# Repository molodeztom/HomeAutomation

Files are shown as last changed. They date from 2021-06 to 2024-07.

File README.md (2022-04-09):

# HomeAutomation
Specifications:
several remote sensors with ESP8266 type a with temperature type b with humidity and temperature
remote sensors shall save energy thus using sleep mode and esp-now protocol
remote sensors report battery voltage
home server as receiver for esp-now and in combination with serial connection to weather station acts as bridge between esp-now and wifi
weather station as receiver, displays values on OLED and provides MQTT messages with measurement values
MQTT is received on a raspberry
raspberry with docker images uses node-red to write mqtt measurements to influx db. Displays values from influx db in grafana.
valve control is esp8266 hardware controlling a valve for central heating goal is to reduce warm water input depending on room temperatures and each radiator valve
remote display is a simple mqtt receiver with OLED to display outdoor temp and humidity

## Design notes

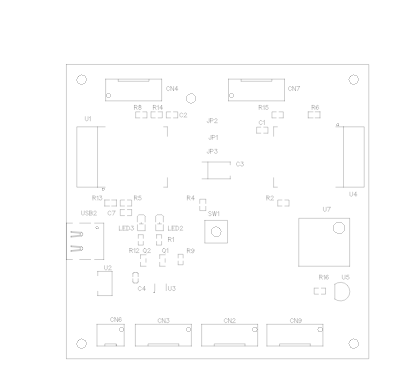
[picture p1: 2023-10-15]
HubESPNow/EasyEDA/PCB_PCB_EspNowHub_2023-02-25.png

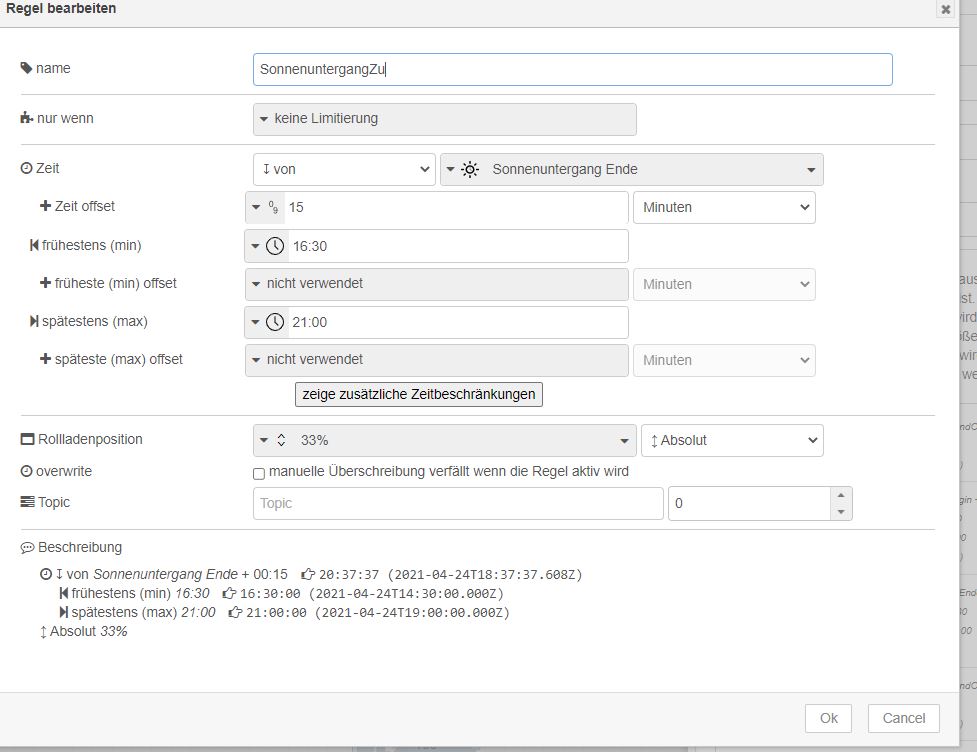
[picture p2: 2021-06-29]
ShutterControl/SonnenUntergangZuTüre.JPG

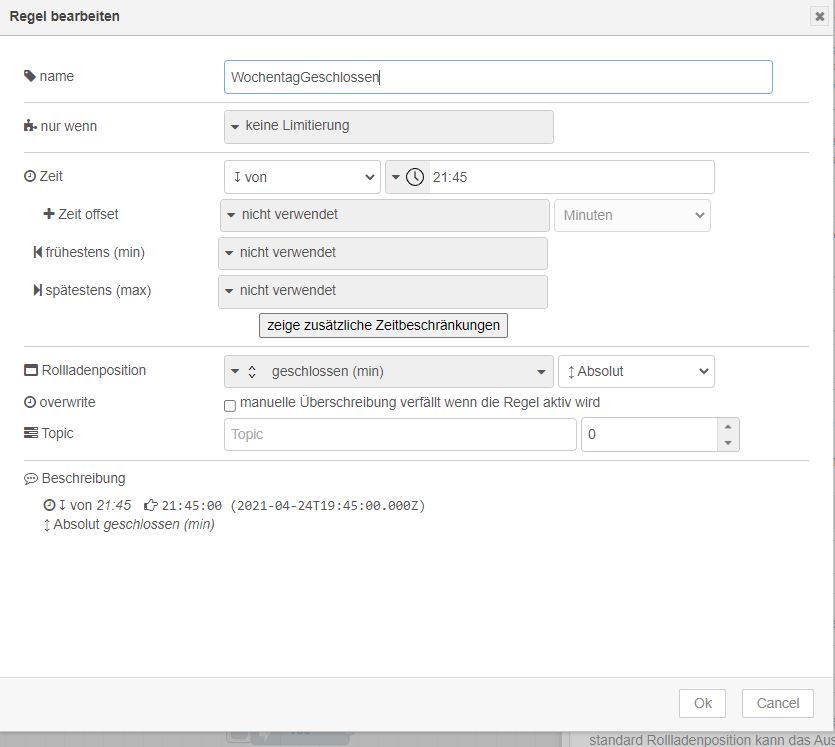
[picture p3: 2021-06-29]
ShutterControl/WochentagGeschlossenTür.JPG

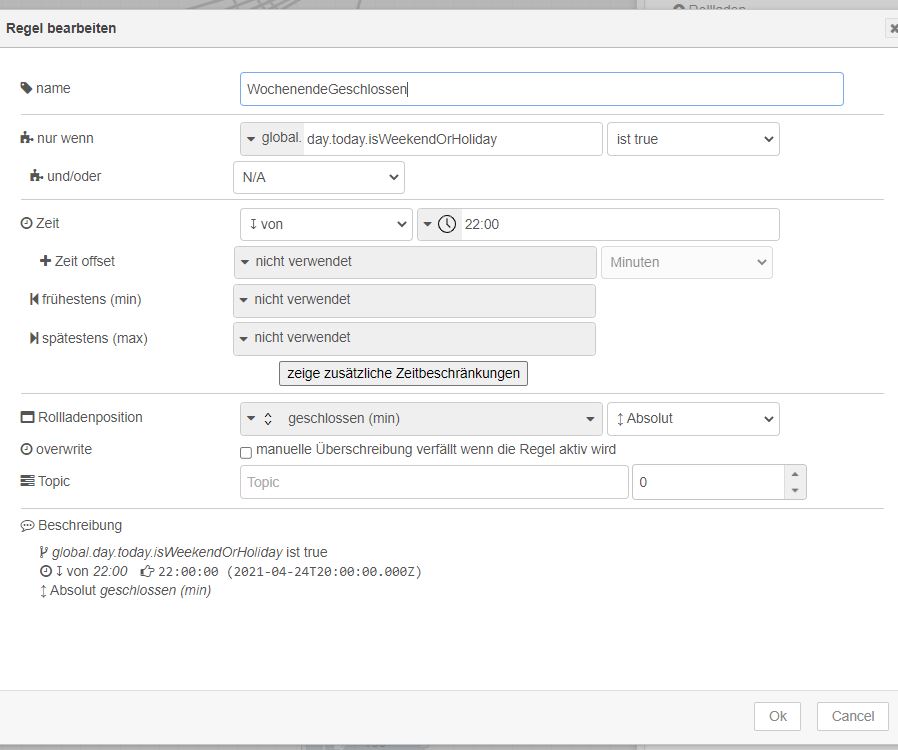
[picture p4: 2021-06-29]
ShutterControl/WochenendeGeschlossenTür.JPG

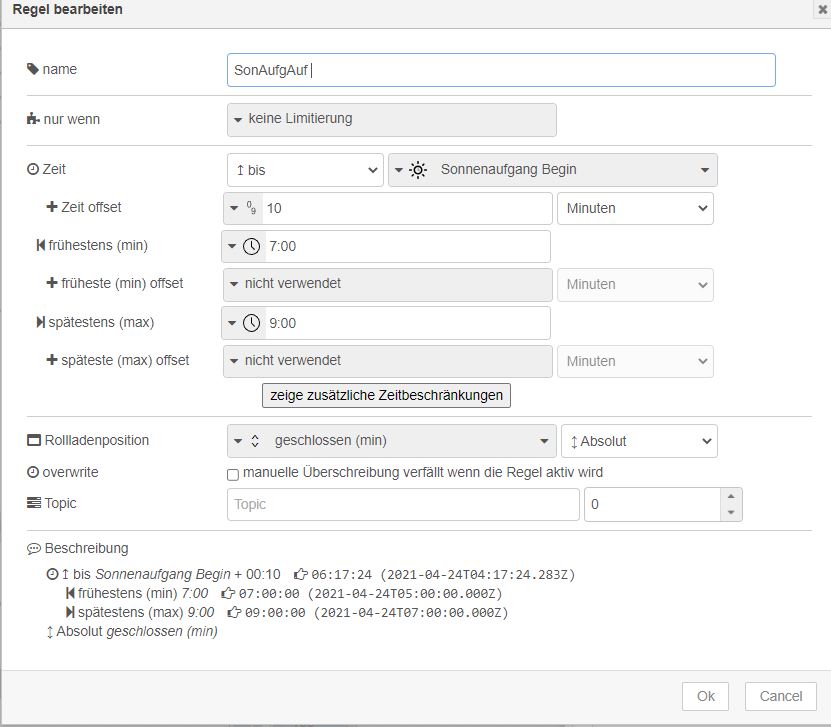
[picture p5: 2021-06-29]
ShutterControl/SonAufgAufTüre.JPG

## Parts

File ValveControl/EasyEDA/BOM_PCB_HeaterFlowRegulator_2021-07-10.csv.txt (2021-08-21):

ID	Name	Designator	Footprint	Quantity	Pins
1	12V ok	12V	LED-SMD_L3.2-W2.8-R-RD	1	2
2	5V ok	5V	LED-SMD_L3.2-W2.8-R-RD	1	2
3	3V ok	3V	LED-SMD_L3.2-W2.8-R-RD	1	2
4	442	R10	R0603	1	2
5	91	R11	R0603	1	2
6	LM358PSR	U5	SOIC-8_L6.2-W5.3-P1.27-LS8.0-BL	1	8
7	Program	CN6	CONN-TH_B5B-XH-AM (LF)(SN)	1	5
8	Reset	SW1	KEY-SMD_4P-L6.0-W6.0-P4.50-LS10.0	1	4
9	ESP8266-12E	U1	LGA22-2.0-24X16MM	1	22
10	Fuse 1A	F1	FUSE-TH_L22.6-W9.0	1	2
11	ext Sensor	TEMP1,TEMP2	CONN-TH_3P-P2.50_B3B-XH-AM(LF)(SN)	2	3
12	MCP4725A0T-E/CH	U4	SOT-23-6_L2.9-W1.6-P0.95-LS2.8-BR	1	6
13	10K	R3,R2	603	2	2
14	10K	R6,R5,R4	603	3	2
15	100nF	C2,C4	C0603	2	2
16	LF33CDT-TR	U2	TO-252-2_L6.6-W6.1-P4.57-LS9.9-BR-CW	1	3
17	0	R7,R8	R0603	2	2
18	PA001-2P	CN4,CN3	CONN-TH_2P-P5.08_PA001-2P	2	2
19	100nF	C6	603	1	2
20	100nF	C7	603	1	2
21	0	R12,R9	R0603	2	2
22	10k	RP1	RES-ADJ-TH_3386P	1	3
23	Tenstar_PSU	PSU1,PSU2	AC-DC PSU 5V/3W	2	4
24	Display	CN7	CONN-TH_B5B-XH-AM (LF)(SN)	1	5
25	Valve Ctrl	CN2	CONN-TH_2P-P5.08_PA001-2P	1	2
26	AC 220V	CN1	CONN-TH_2P-P5.08_PA001-2P	1	2
27	LightSensor	CN8	CONN-TH_B5B-XH-AM (LF)(SN)	1	5
28	220uF	C1,C3	CAP-TH_BD8.0-P3.50-D0.6-FD	2	2
29	100uF	C5	CAP-SMD_L3.5-W2.8	1	2

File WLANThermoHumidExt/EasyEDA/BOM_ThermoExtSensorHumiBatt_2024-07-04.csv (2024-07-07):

ID | Name | Designator | Footprint | Quantity | Manufacturer Part | Manufacturer | Supplier | Supplier Part | Price
1 | 100nF | C1,C3,C4,C5,C11 | 0603 | 5 | CL10B104KC8NNNC | SAMSUNG | LCSC | C15725 | 0.007
2 | 100uF | C2 | CAP-SMD_L7.3-W4.3 | 1 | TAJB107K006RNJ | AVX | LCSC | C16133 | 0.142
3 | 1uF | C6,C7 | C0603 | 2 | CL10A105KA8NNNC | SAMSUNG | LCSC | C5673 | 0.004
4 | 100nF | C8 | C0603 | 1 | CL10F104ZB8NNNC | SAMSUNG | LCSC | C1688 | 0.005
5 | 10uF | C9,C10 | C1206 | 2 | CL31A106KAHNNNE | SAMSUNG | LCSC | C9807 | 0.019
6 | Program | CN1 | CONN-TH_B5B-XH-AM (LF)(SN) | 1 | - | JST Sales America | LCSC | C161872 | 0.088
7 | B2B-XH-AM (LF)(SN) | CN3 | CONN-TH_B2B-XH-AM (LF)(SN) | 1 | - | JST Sales America | LCSC | C161869 | 0.052
8 | SS14_C84343 | D2 | SMA_L4.3-W2.6-LS5.2-RD | 1 | SS14 | STARSEA | LCSC | C84343 | 0.023
9 | green | LED3 | LED0805-FD | 1 | FC-2012UGK-520D5 | NATIONSTAR | LCSC | C84260 | 0.019
10 | red | LED4 | LED0805-FD | 1 | FC-2012UGK-520D5 | NATIONSTAR | LCSC | C84260 | 0.019
11 | 8205A | Q2 | TSSOP-8_L4.4-W3.0-P0.65-LS6.4-BL | 1 | 8205A | Hottech | LCSC | C181100 | 0.059
12 | 10K | R1,R2,R3,R4,R5,R6 | 0603 | 6 | TC0325B1002T5E | UniOhm | LCSC | C39050 | 0.041
13 | 100K | R7 | R0603 | 1 | TC0350B1003T5E | UNI-ROYAL(Uniroyal Elec) | LCSC | C415126
14 | 1K | R8,R14,R15 | R0603 | 3 | TC0350D1001T5E | Uniroyal Elec | LCSC | C165976 | 0.008
15 | 100 | R9 | R0603 | 1 | TC0325B1000T5E | UniOhm | LCSC | C54021 | 0.036
16 | 4.7K | R10 | R0603 | 1 | TC0325B4701T5E | UniOhm | LCSC | C148464 | 0.056
17 | 0 | R11,R12 | R0603 | 2 | 0603WAJ0000T5E | UniOhm | LCSC | C15402 | 0.001
18 | 1.2K | R17 | R0603 | 1 | AR03DTCX1201 | Viking Tech | LCSC | C319998 | 0.013
19 | Reset | SW1 | KEY-SMD_4P-L6.0-W6.0-P4.50-LS10.0 | 1 | TL3301TF160QG/D310794 | E-Switch | LCSC | C273532 | 0.465
20 | ext Sensor | TEMP | CONN-TH_3P-P2.50_B3B-XH-AM(LF)(SN) | 1 | B3B-XH-AM-(LF)(SN) | JST Sales America | LCSC | C161870 | 0.063
21 | ESP8266-12E | U1 | LGA22-2.0-24X16MM | 1 | ESP8266-12E/ESP-12E |  | SeeedStudio | 317060015
22 | DS18B20 | U2 | TO-92(TO-92-3) | 1 | DS18B20+ | MAXIM | LCSC | C9753 | 1.107
23 | XC6206P332MR | U3 | SOT-23-3_L2.9-W1.6-P1.90-LS2.8-BR | 1 | XC6206P332MR | TOREX | LCSC | C5446 | 0.097
24 | DW01A-G | U4 | SOT-23-6_L2.9-W1.6-P0.95-LS2.8-BR | 1 | DW01A-G | FORTUNE | LCSC | C61503 | 0.125
25 | DHT22 | U6 | DHT22_AM2303_VERT | 1 |  | Aosong (Guangzhou) Electronics Co., Ltd. | AdaFruit | PRODUCT ID: 385
26 | MAX708SESA-TG | U7 | SOIC-8_L4.9-W3.9-P1.27-LS6.0-BL | 1 | MAX708SESA-TG | ON Semicon | LCSC | C233649
27 | TP4056_C382139 | U8 | ESOP-8_L4.9-W3.9-P1.27-LS6.0-BL-EP | 1 | TP4056 | TPOWER | LCSC | C382139 | 0.094
28 | USB-306 | USB1 | USB-TYPE-C-TH_USB-306 | 1 | USB-306 | HOOYA | LCSC | C309338 | 0.607

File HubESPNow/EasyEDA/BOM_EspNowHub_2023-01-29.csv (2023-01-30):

ID | Name | Designator | Footprint | Quantity | Manufacturer Part | Manufacturer | Supplier | Supplier Part | Price
1 | 100nF | C1,C2 | 0603 | 2 | CL10B104KC8NNNC | SAMSUNG | LCSC | C1688 | 0.001
2 | 100uF | C3 | CAP-SMD_L7.3-W4.3-R-RD | 1 | CA45-D-16V-100UF-K | CEC | LCSC | C129274 | 0.068
3 | 100nF | C4 | C0603 | 1 | CL10B104KC8NNNC | SAMSUNG | LCSC | C1688 | 0.001
4 | 100nF | C7 | 0603 | 1 | CL10B104JB8NNNC | SAMSUNG | LCSC | C1688 | 0.001
5 | LightSensor | CN2 | CONN-TH_B5B-XH-AM (LF)(SN) | 1 | - | JST Sales America | LCSC | C161872 | 0.015
6 | Display | CN3,CN9 | CONN-TH_B5B-XH-AM (LF)(SN) | 2 | - | JST Sales America | LCSC | C161872 | 0.015
7 | Program 2 | CN4 | CONN-TH_B5B-XH-AM (LF)(SN) | 1 | - | JST Sales America | LCSC | C161872 | 0.015
8 | +5V Batt | CN6 | CONN-TH_B2B-XH-AM-LF-SN | 1 | - | JST Sales America | LCSC | C161869 | 0.009
9 | Program 1 | CN7 | CONN-TH_B5B-XH-AM (LF)(SN) | 1 | - | JST Sales America | LCSC | C161872 | 0.015
10 | RX | JP1 | SPARKFUN-JUMPERS_SMT-JUMPER_2_NC_PASTE_NO-SILK | 1
11 | TX | JP2 | SPARKFUN-JUMPERS_SMT-JUMPER_2_NC_PASTE_NO-SILK | 1
12 | RX Ext | JP3 | SPARKFUN-JUMPERS_SMT-JUMPER_2_NC_PASTE_NO-SILK | 1
13 | 3V OK red | LED2 | LED0805-R-RD | 1 | 17-21SURC/S530-A3/TR8 | EVERLIGHT | LCSC | C72037 | 0.003
14 | 5V USB blue | LED3 | LED0805-R-RD | 1 | FC-2012UGK-520D5 | NATIONSTAR | LCSC | C84260 | 0.003
15 | DMP1045U-7 | Q1,Q2 | SOT-23-3_L2.9-W1.3-P1.90-LS2.4-BR | 2 | DMP1045U-7 | Diodes Incorporated | LCSC | C177033 | 0.061
16 | 210Ω | R1 | R0603 | 1 | 0603WAF2100T5E | UniOhm | LCSC | C22953
17 | 10K | R2,R14,R16 | 0603 | 3 | TC0325B1002T5E | UniOhm | LCSC | C39050 | 0.006
18 | 10K | R4,R5,R8,R15 | 0603 | 4 | TC0310B1002T5E | Uniroyal Elec | LCSC | C190321 | 0.024
19 | 1MΩ | R9 | R0603 | 1 | 0603WAF1004T5E | UniOhm | LCSC | C22935
20 | 130Ω | R12 | R0603 | 1 | 0603WAF1300T5E | UniOhm | LCSC | C22796
21 | Reset | SW1 | KEY-SMD_4P-L6.0-W6.0-P4.50-LS10.0 | 1 | TL3301TF160QG/D310794 | E-Switch | LCSC | C273532 | 0.083
22 | ESP8266-12E WLAN | U1 | LGA22-2.0-24X16MM | 1 | ESP8266-12E/ESP-12E |  | SeeedStudio | 317060015
23 | AMS1117-3.3 | U2 | PG-SOT223-4_L6.5-W3.5-P2.30-LS7.0-BR | 1 | AMS1117-3.3 | HGC(Huaguan Semicon) | LCSC | C498117
24 | LTC4412ES6 | U3 | TSOT-23-6_L2.9-W1.6-P0.95-LS2.8-BR | 1 | LTC4412ES6#TRPBF | Analog Devices | LCSC | C514442 | 0.467
25 | ESP8266-12E ESP NOW | U4 | LGA22-2.0-24X16MM | 1 | ESP8266-12E/ESP-12E |  | SeeedStudio | 317060015
26 | DS18B20 | U5 | TO-92(TO-92-3) | 1 | DS18B20+ | MAXIM | LCSC | C9753 | 0.195
27 | BMP180 | U7 | BMP180 | 1 | PROJ_LIC Lib
28 | USB-306 | USB2 | USB-TYPE-C-TH_USB-306. | 1 | USB-306 | HOOYA | LCSC | C309338 | 0.099

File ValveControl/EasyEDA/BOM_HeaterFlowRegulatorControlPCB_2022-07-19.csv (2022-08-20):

Designator | Quantity | Name | ID
C1,C2 | 2 | 100nF | 1
CN1 | 1 | In | 2
CN2 | 1 | Out | 3
LED1 | 1 | LED1 rd | 4
LED2 | 1 | LED2 gn | 5
LED3 | 1 | LED3 ye | 6
LED4 | 1 | LED4 bl | 7
Q1,Q2 | 2 | BSS138 | 8
R1,R3 | 2 | 91 | 9
R2,R4 | 2 | 150 | 10
R8,R9,R10 | 3 | 0 | 11
R11,R12,R13,R14 | 4 | 10K | 12
SW1 | 1 | SW1 | 13
SW2 | 1 | SW2 | 14
SW3 | 1 | SW3 | 15
SW4 | 1 | SW4 | 16
U10 | 1 | PCF8574T | 17

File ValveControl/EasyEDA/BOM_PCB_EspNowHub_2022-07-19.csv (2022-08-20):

Designator | Quantity | Name | ID
C1,C2,C7 | 3 | 100nF | 3
C3 | 1 | 100uF | 25
C4 | 1 | 100nF | 5
CN2 | 1 | LightSensor | 6
CN3,CN9 | 2 | Display | 7
CN4 | 1 | Program 2 | 8
CN6 | 1 | +5V Batt | 10
CN7 | 1 | Program 1 | 9
JP1 | 1 | RX | 11
JP2 | 1 | TX | 12
JP3 | 1 | RX Ext | 13
LED2 | 1 | 3V OK red | 14
LED3 | 1 | 5V USB blue | 15
Q1,Q2 | 2 | DMP1045U-7 | 16
R1 | 1 | 210Ω | 17
R12 | 1 | 130Ω | 18
R2,R4,R5,R8,R14,R15,R16 | 7 | 10K | 4
R9 | 1 | 1MΩ | 19
SW1 | 1 | Reset | 1
U1 | 1 | ESP8266-12E WLAN | 20
U2 | 1 | AMS1117-3.3 | 22
U3 | 1 | LTC4412ES6 | 23
U4 | 1 | ESP8266-12E ESP NOW | 21
U5 | 1 | DS18B20 | 24
U7 | 1 | BMP180 | 26
USB2 | 1 | USB-306 | 2

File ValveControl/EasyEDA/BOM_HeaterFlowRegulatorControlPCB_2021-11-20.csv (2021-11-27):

ID | Name | Designator | Footprint | Quantity | Pins
1 | 100nF | C1,C2 | 603 | 2 | 2
2 | In | CN1 | CONN-TH_B5B-XH-AM (LF)(SN) | 1 | 5
3 | Out | CN2 | CONN-TH_B5B-XH-AM (LF)(SN) | 1 | 5
4 | LED1 | LED1 | LED-SMD_L3.2-W2.8-LS3.5-FD | 1 | 2
5 | LED2 | LED2 | LED-SMD_L3.2-W2.8-LS3.5-FD | 1 | 2
6 | LED3 | LED3 | LED-SMD_L3.2-W2.8-LS3.5-FD | 1 | 2
7 | LED4 | LED4 | LED-SMD_L3.2-W2.8-LS3.5-FD | 1 | 2
8 | BSS138 | Q1,Q2 | SOT-23-3_L3.0-W1.7-P0.95-LS2.9-BR | 2 | 3
9 | 2K | R1,R2,R3,R4 | R0603 | 4 | 2
10 | 0 | R5,R6,R7,R8,R9,R10 | R0603 | 3 | 2
11 | 10K | R11,R12,R13,R14 | 603 | 4 | 2
12 | SW1 | SW1 | KEY-SMD_4P-L6.0-W6.0-P4.50-LS10.0 | 1 | 4
13 | SW2 | SW2 | KEY-SMD_4P-L6.0-W6.0-P4.50-LS10.0 | 1 | 4
14 | SW3 | SW3 | KEY-SMD_4P-L6.0-W6.0-P4.50-LS10.0 | 1 | 4
15 | SW4 | SW4 | KEY-SMD_4P-L6.0-W6.0-P4.50-LS10.0 | 1 | 4
16 | PCF8574T | U10 | SOP-16_L10.3-W7.5-P1.27-LS10.4-BL | 1 | 16

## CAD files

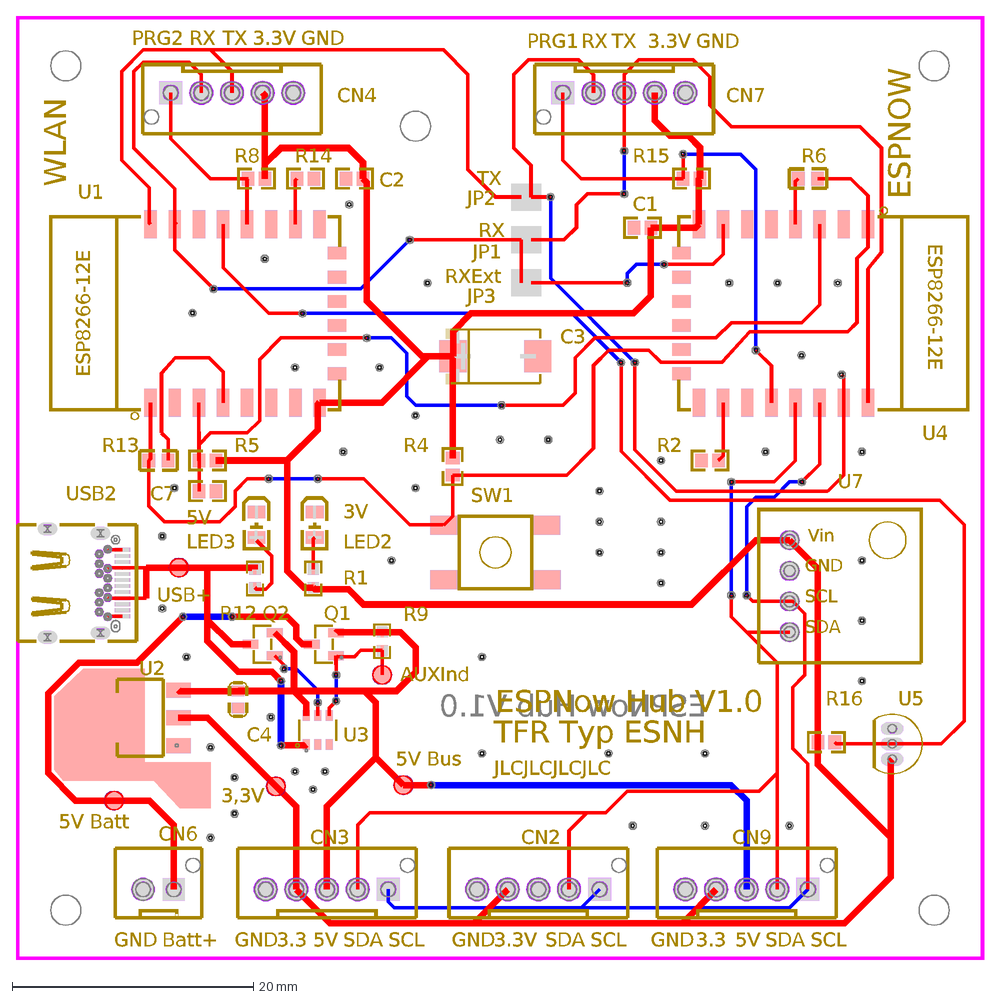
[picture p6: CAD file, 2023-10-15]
HubESPNow/EasyEDA/PCB_EspNowHub_2023-02-25.dxf
ESPNow Hub V1.0
USB+
AUXInd
5V Bus
3,3V
5V Batt
JLCJLCJLCJLC
TFR Typ ESNH
3V
5V
TX
RX
RXExt
WLAN
ESPNOW
GND
Batt+
3.3
SDA
SCL
3.3V
PRG2
PRG1
ESP8266-12E
SW1
USB2
C1
C2
C7
R2
R4
R5
R8
R14
R15
R16
C4
CN2
CN3
CN4
CN7
CN9
CN6
JP1
JP2
JP3
LED2
LED3
Q1
Q2
R1
R12
R6
R13
R9
U1
U4
U2
U3
U5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

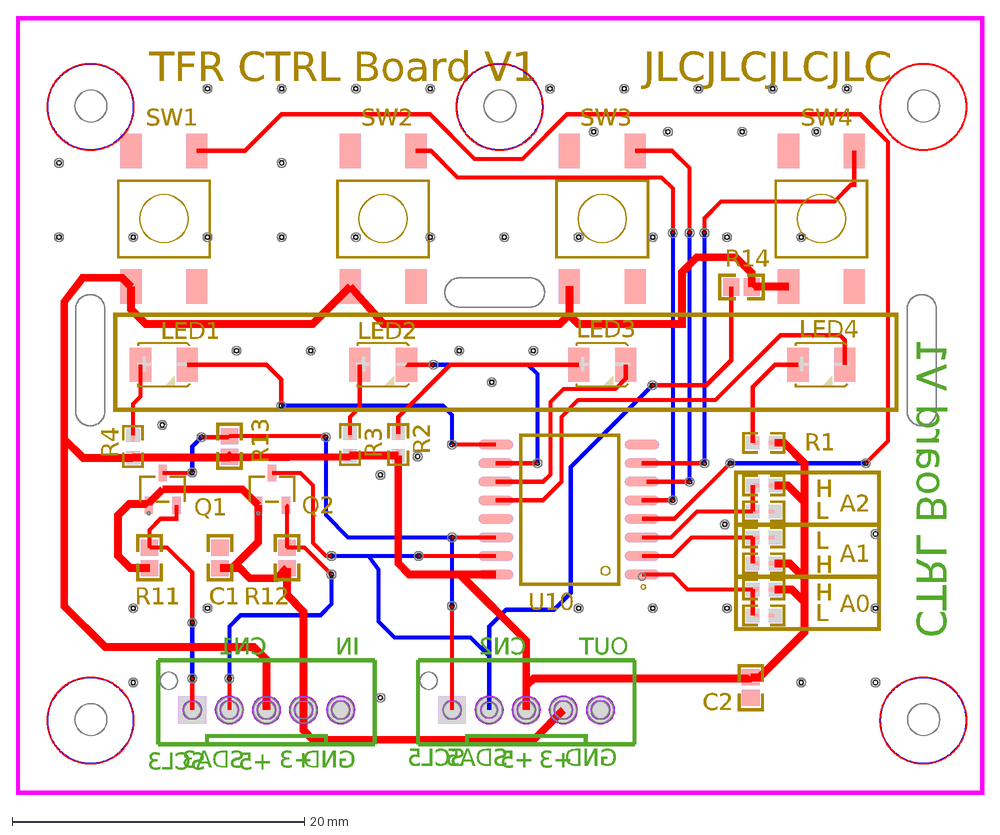
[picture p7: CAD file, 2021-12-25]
ValveControl/EasyEDA/ControlPCB.dxf
CTRL Board V1
OUT
IN
GND
+5
SDA5
SCL5
SDA3
SCL3
+3
A0
A1
A2
JLCJLCJLCJLC
TFR CTRL Board V1
CN1
CN2
LED1
LED2
LED3
LED4
Q1
Q2
R2
R3
R4
H
L
R11
R12
R13
R14
SW1
SW2
SW3
SW4
U10
C1
R1
C2

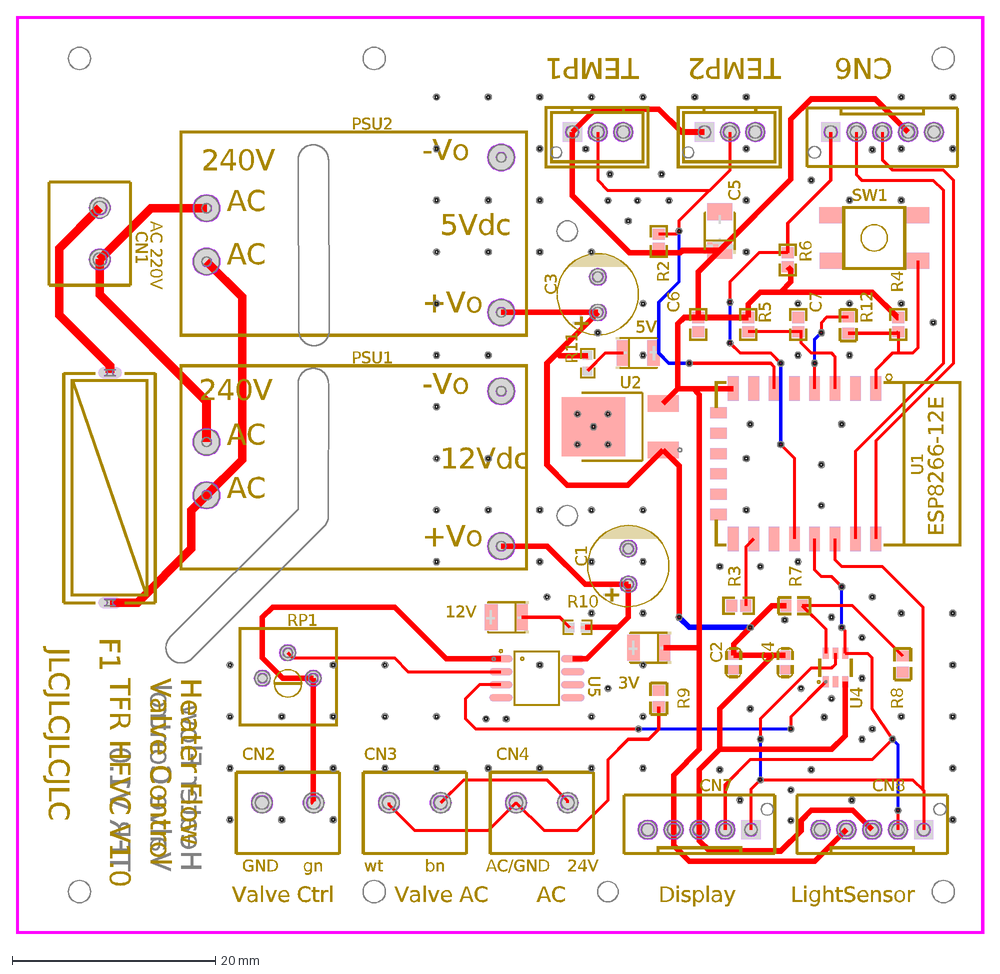
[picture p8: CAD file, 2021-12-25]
ValveControl/EasyEDA/PCB_HeaterFlowRegulator_2021-12-02.dxf
Heater Flow
Valve Control
TFR V1.0
ESP8266-12E
LightSensor
Display
Valve AC
Valve Ctrl
AC
24V
AC/GND
gn
GND
bn
wt
TFR HFVC V1.0
JLCJLCJLCJLC
12V
5V
3V
R10
R11
U5
CN6
SW1
U1
F1
TEMP1
TEMP2
U4
R3
R6
R2
R5
R4
C2
C4
U2
R7
R8
CN4
CN3
C6
C7
R12
RP1
PSU1
-Vo
+Vo
240V
12Vdc
CN7
R9
CN2
AC 220V
CN1
CN8
PSU2
5Vdc
C1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

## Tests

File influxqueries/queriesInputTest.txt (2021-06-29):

# DDL
DROP CONTINUOUS QUERY cq_5min_SLoc_fHumi ON HomeAutomation
DROP CONTINUOUS QUERY cq_5min_SLoc_fAtmo ON HomeAutomation

# DML

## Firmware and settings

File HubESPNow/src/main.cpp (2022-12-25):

/*
 
Hardware: 
ESPNowHub V1.0 und CTRL Board V1 mit externem OLED Display und div Sensoren 
Funktion:
Anzeige von div. Werten aus lokalen Sensoren auf OLED
Empfang von externen Temperaturwerten über ESP-Now 
Versenden der Werte über WLAN an Thingspeak
Versenden der Werte in JSON Format an HomeServer über Serial

20220918: V0.1: Neues Projekt aus ESPHubHW Test und WeatherStation main.cpp
20220918: V0.2: Temperatursensor DS18B20 dazu    
20220925  V0.3: remove tempsensor it is connected to ESPWLAN instead
20220925  V0.4: read BMP085 pressure sensor
20220925  V0.5: read "Arbeitszimmer" sensor using ESPNow
20221121  V0.6: remove display demo
20221218  V0.7: remove blinking LEDS
20221218  V0.8: read SW and switch on red led

 */
#include <Arduino.h>
#define DEBUG
#include <ArduinoJson.h>
#include <SoftwareSerial.h>
#include "PCF8574.h"
#include "SSD1306Wire.h"
#include "images.h"

#include <ESP8266WiFi.h>

// BMP085 pressure sensor
#include <Adafruit_SPIDevice.h>
#include "Wire.h"
#include <Adafruit_BMP085.h>

//Bibliothek für ESP-Now
extern "C"
{
#include <espnow.h>
}

//common data e.g. sensor definitions
#include "D:\Projects\HomeAutomation\HomeAutomationCommon.h"


const String sSoftware = "HubESPNow V0.8";

//used to correct small deviances in sensor reading  0.xyz  x=Volt y=0.1Volt z=0.01V3
#define BATTCORR1 -0.099
#define BATTCORR2 -0.018
#define BATTCORR3 -0.018
#define BATTCORR4 -0.018
#define BATTCORR5 -0.21
#define SENSCORR1A -0.25

//struct for exchanging data over ESP NOW
struct DATEN_STRUKTUR
{
  int iSensorChannel = 99;  //default for none received
  float fESPNowTempA = -99; //Aussen A
  float fESPNowTempB = -99; //Aussen B
  float fESPNowHumi = -99;
  float fESPNowVolt = -99; //Batterie Sensor
};

/***************************
 * ESP Now Settings
 **************************/
//SSID Open for some time. Sensors can contact AP to connect. After that time sensor use stored MAC adress
long lAPOpenTime = 0;
const unsigned long ulAPOpenIntervall = 240 * 1000UL; //time in sec
bool APOpen = false;
//ESP Now
void on_receive_data(uint8_t *mac, uint8_t *r_data, uint8_t len);


/* I2C Bus */
// if you use ESP8266-01 with not default SDA and SCL pins, define these 2 lines, else delete them
//  use Pin Numbers from GPIO e.g. GPIO4 = 4
//  For NodeMCU Lua Lolin V3: D1=GPIO5 = SCL D2=GPIO4 = SDA set to SDA_PIN 4, SCL_PIN 5, D7=13
//#define SDA_PIN 4
//#define SCL_PIN 5



/***************************
 * PCF857XC I2C to parallel
 **************************/
int iPCF857XAdr = 0x20;
bool LedOn = false;
bool bKeyPressed = false;
PCF8574 pcf857X(iPCF857XAdr);

/***************************
 * Ctrl PCB Settings
 **************************/
#define LEDGB P6
#define LEDGN P5
#define LEDBL P7
#define LEDRT P4
#define SW4 P0
#define SW3 P1
#define SW2 P2
#define SW1 P3

long lswitchReadTime = 0;
const unsigned long ulSwitchReadInterval =  0.3 * 1000UL; //Time until switch is read next time in s

/***************************
 * Display Settings
 **************************/

const int I2C_DISPLAY_ADDRESS = 0x3c;

const int SDA_PIN = D2;
const int SCL_PIN = D1;
//const int SDA_PIN = D3; //GPIO0
//const int SCL_PIN = D4; //GPIO2

// Initialize the oled display for address 0x3c
SSD1306Wire display(0x3c,SDA_PIN,SCL_PIN);

// Forward declarations
// flag changed in the ticker function every 10 minutes

void ledOn(uint8_t LedNr);
void ledOff(uint8_t LedNr);


/***************************
 * Begin Atmosphere and iLightLocal Sensor Settings
 **************************/
//void readLight();
void readAtmosphere();
Adafruit_BMP085 bmp;
//const int Light_ADDR = 0b0100011;                      // address:0x23
//const int Atom_ADDR = 0b1110111;                       // address:0x77
long lreadTime = 0;
const unsigned long ulSensReadIntervall = 70 * 1000UL; //Time to evaluate received sens values for display

int ledNr = 0;

void setup()
{
  Serial.begin(115200);
  Serial.println(sSoftware);
  pinMode(LED_BUILTIN, OUTPUT);
  // WIFI ESPNOW
  WiFi.persistent(false); //https://www.arduinoforum.de/arduino-Thread-Achtung-ESP8266-schreibt-bei-jedem-wifi-begin-in-Flash
 //Reset WiFI
  WiFi.disconnect();
  WiFi.mode(WIFI_AP);
  WiFi.begin();
  //AP for sensors to ask for station MAC adress
  WiFi.softAP(APSSID);
  Serial.println("Start AP");
  Serial.println(APSSID);
  APOpen = true;
  lAPOpenTime = millis();
  delay(1000);

  if (esp_now_init() != 0)
  {
    Serial.println("Init ESP-Now failed restart");
    ESP.restart();
  }
  // ESP Role  1=Master, 2 = Slave 3 = Master + Slave
  Serial.println("Set espnow Role 2");
  esp_now_set_self_role(2);
  //callback for received ESP NOW messages
  esp_now_register_recv_cb(on_receive_data);

  //initialize Atmosphere sensor
  if (!bmp.begin())
  {
    Serial.println("Could not find BMP180 or BMP085 sensor at 0x77");
  }
  else
  {
    Serial.println("Found BMP180 or BMP085 sensor at 0x77");
  }



  // initialize pcf8574
  pcf857X.begin();
  pcf857X.pinMode(SW4, INPUT);
  pcf857X.pinMode(SW3, INPUT);
  pcf857X.pinMode(SW1, INPUT);
  pcf857X.pinMode(SW2, INPUT);
  pcf857X.pinMode(LEDRT, OUTPUT);
  pcf857X.pinMode(LEDGN, OUTPUT);
  pcf857X.pinMode(LEDGB, OUTPUT);
  pcf857X.pinMode(LEDBL, OUTPUT);
  
  // LED Test
  ledOn(LEDRT);
  ledOn(LEDGN);
  ledOn(LEDGB);
  ledOn(LEDBL);
  delay(2000);
  ledOff(LEDRT);
  ledOff(LEDGN);
  ledOff(LEDGB);
  ledOff(LEDBL);
  

   // initialize display
  display.init();
  //display.displayOn();
  display.flipScreenVertically();
  display.setFont(ArialMT_Plain_10);
 // display.setTextAlignment(TEXT_ALIGN_CENTER);
 // display.setContrast(255);
    display.drawString(2, 10, sSoftware);
    display.display();
    delay(2500);

    
  Serial.println("setup end");

}

void loop()
{

// clear the display
 
  display.clear();
  display.setFont(ArialMT_Plain_10);
  display.setTextAlignment(TEXT_ALIGN_RIGHT);
  display.drawString(128, 54, String(millis()));
  // write the buffer to the display
  display.display();
   //Close Wifi AP after some time

  if ((millis() - lAPOpenTime > ulAPOpenIntervall) && APOpen == true)
  {
    WiFi.softAPdisconnect();
 
    APOpen = false;
#ifdef DEBUG
    Serial.println("AP disconnect");
#endif
  }

//Read local sensors pressure and light every x seconds
  if (millis() - lreadTime > ulSensReadIntervall)
  {
    Serial.println("Readlocal");
   // readLight();
    readAtmosphere();
   // formatTempExt();

    lreadTime = millis();
  }

  //Read input switches every x seconds
  if (millis() - lswitchReadTime > ulSwitchReadInterval)
  {
    Serial.println("ReadSwitches");
if(pcf857X.digitalRead(SW4) == HIGH)
{
    ledOn(LEDRT);
}

    lreadTime = millis();
  }

  //Every x seconds check sensor readings, if no reading count up and then do not display
  if ((millis() - lSensorValidTime > ulSensorValidIntervall))
  {
    Serial.println("Sensor count up");
    sSensor1.iSensorCnt++;
    sSensor2.iSensorCnt++;
    sSensor3.iSensorCnt++;
    //sSensor4.iSensorCnt++;
    sSensor5.iSensorCnt++;
    lSensorValidTime = millis();
  }




}

//Callback funktion wenn Daten über ESP-Now empfangen wurden
void on_receive_data(uint8_t *mac, uint8_t *r_data, uint8_t len)
{

  DATEN_STRUKTUR sESPReceive;
   //copy received data to struct, to get access via variables
  memcpy(&sESPReceive, r_data, sizeof(sESPReceive));
  //TODO check values and send further only if correct
  //iSensorChannel = sESPReceive.iSensorChannel;
#ifdef DEBUG
  Serial.print("Channel: ");
  Serial.println(sESPReceive.iSensorChannel);
#endif

  //depending on channel
  switch (sESPReceive.iSensorChannel)
  {
  case 1:
    sSensor1.fTempA = roundf((sESPReceive.fESPNowTempA + SENSCORR1A) * 100) / 100;
    sSensor1.fHumi = roundf(sESPReceive.fESPNowHumi * 100) / 100;
    sSensor1.fVolt = roundf((sESPReceive.fESPNowVolt + BATTCORR1) * 100) / 100;
    sSensor1.bSensorRec = true;
    sSensor1.iSensorCnt = 0;

#ifdef DEBUG
    Serial.print("Temperatur 1A: ");
    Serial.println(sSensor1.fTempA);
    Serial.print("extHumidity: ");
    Serial.println(sSensor1.fHumi);
    Serial.print("Batt1 V: ");
    Serial.println(sSensor1.fVolt);
#endif
    break;
  case 2:
    sSensor2.fTempA = roundf(sESPReceive.fESPNowTempA * 100) / 100;
    sSensor2.fVolt = roundf((sESPReceive.fESPNowVolt + BATTCORR2) * 100) / 100;
    sSensor2.bSensorRec = true;
    sSensor2.iSensorCnt = 0;
#ifdef DEBUG
    Serial.println("Recieved Data 2");
    Serial.print("Temperatur 2A: ");
    Serial.println(sSensor2.fTempA);
    Serial.print("Batt2 V: ");
    Serial.println(sSensor2.fVolt);
#endif
    break;
  case 3:
    sSensor3.fTempA = roundf(sESPReceive.fESPNowTempA * 100) / 100;
    sSensor3.fVolt = roundf((sESPReceive.fESPNowVolt + BATTCORR3) * 100) / 100;
    sSensor3.bSensorRec = true;
    sSensor3.iSensorCnt = 0;
#ifdef DEBUG
    Serial.println("Recieved Data 3");
    Serial.print("Temperatur 3: ");
    Serial.println(sSensor3.fTempA);
    Serial.print("Batt3 V: ");
    Serial.println(sSensor3.fVolt);
#endif
    break;
  case 4:
    sSensor4.fTempA = roundf(sESPReceive.fESPNowTempA * 100) / 100;
    sSensor4.fVolt = roundf((sESPReceive.fESPNowVolt + BATTCORR4) * 100) / 100;
    sSensor4.fHumi = roundf(sESPReceive.fESPNowHumi * 100) / 100;
    sSensor4.bSensorRec = true;
    sSensor4.iSensorCnt = 0;
#ifdef DEBUG
    Serial.println("Recieved Data 4");
    Serial.print("Temperatur 4: ");
    Serial.println(sSensor4.fTempA);
    Serial.print("Batt4 V: ");
    Serial.println(sSensor4.fVolt);
    Serial.print("extHumidity: ");
    Serial.println(sSensor4.fHumi);
#endif

    break;
  case 5:
    sSensor5.fTempA = roundf(sESPReceive.fESPNowTempA * 100) / 100;
    sSensor5.fVolt = roundf((sESPReceive.fESPNowVolt + BATTCORR5) * 100) / 100;
    sSensor5.fHumi = roundf(sESPReceive.fESPNowHumi * 100) / 100;
    sSensor5.bSensorRec = true;
    sSensor5.iSensorCnt = 0;
#ifdef DEBUG
    Serial.println("Recieved Data 5");
    Serial.print("Temperatur 5: ");
    Serial.println(sSensor5.fTempA);
    Serial.print("Batt5 V: ");
    Serial.println(sSensor5.fVolt);
    Serial.print("extHumidity: ");
    Serial.println(sSensor5.fHumi);
#endif

    break;
  default:
    Serial.println("Default Channel do nothing");
    break;
  }
};


// function LED on off
void ledOn(uint8_t LedNr)
{
  pcf857X.digitalWrite(LedNr, LOW);
}
void ledOff(uint8_t LedNr)
{
  pcf857X.digitalWrite(LedNr, HIGH);
}


//BMP180 pressure sensor

void readAtmosphere()
{

  sSensor0.fAtmo = bmp.readPressure();
  sSensor0.fAtmo = sSensor0.fAtmo / 100;

#ifdef DEBUG
  int bmpTemp;
  bmpTemp = bmp.readTemperature();
  Serial.print("Pressure = ");
  Serial.print(sSensor0.fAtmo);
  Serial.println(" Pascal");
  Serial.print("BMP Temp = ");
  Serial.println(bmpTemp);
#endif
}

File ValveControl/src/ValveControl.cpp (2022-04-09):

/**************************************************************************
Home Automation Project
   Valve Control for central heating 

  Hardware: 
  ESP Node MCU 0.1
  MCP4725A1 I2C to 0 - 5 V DC output
  LMxx to amplify 0-5 V DC to 0-10 V DC
  
  Connect to MQTT Server and subscribe valve closing rate
  control. Measure IN and OUT Temp. Display values on LCD. Send Temp Values with MQTT. 

  History: master if not shown otherwise
  20200509  V0.1:  Copy from Adafruit example for MCP4725A1
  20200510  V0.2:  Output 3 fixed values to test valve behaviour
  20200510  V0.3:  Get SetPoint as MCP digits from MQTT as int and set valve accordingly
  20201019  V0.4:  Converted to visual studio code project
  20201230  V0.5:  Include secrets.h software string output (valveCurTest)
                   + INA219 sensor tests sucessfull (valveCurTest)
                   + Temperature Sensor 1 added
                   c publish current values via mqtt
  20201230  V0.6:  +LCD display with hello world
  20210101  V0.7:  c Values for valve 0-5 instead of 4095
  20210101  V0.8:  + Watchdog for MQTT and error msg display send errors with MQTT to server 
  20210101  V0.9:  b ActValue leading blanks removed
  20210102  V0.10: + Light sensor GY-302 BH1750, switch off LCD backlight when dark (sic)
  20210102  V0.11: + tactile switch for manual valve select
  20210102  V0.12: + on valve pos 1-2 use pos 3 but open and close in timed intervalls 
  20210821  V0.13: c PCB Hardware introduced testing 
  20210821  V0.14: + OTA
  20210826  V0.15: + PC875 parallel to I2C interface
  20210828  V0.16: + https://github.com/xreef/PCF8575_library
  20210829  V0.17: c use PC8575 lib for breadboard tests
  20210829  V0.18: c Input with tactile switch over PC857x now working, debut codes removed
  20210829  V0.19: c Lightsensor back to code
  20210830  V0.20: c Timing back to original values (due to mqtt connect errors), Valve ON display bug corrected
  20210830  V0.21: + ErrorNumber to reset errors specifically
  20211127  V0.22: c Adapt to Ctrl PCB disable Switch and test LEDs with running light
  20211127  V0.23: c Switch LED 1 according to switch 1
  20211230  V0.24: c LED with defines, LED with function
  20211230  V0.25: c LED according to function
  20211230  V0.26: c Switches according to function
  20211231  V0.27: c Light sensor less 
  20211231  V1.00: i Released and working fixed on wall, MQTT Man Auto Mode published, start with Auto Mode
  20220101  V1.01: c On interval mode open to pos 3 instead of 5, mode1 off time greater than on time
  20220102  V1.02: b Mode1 changed interval handling, off time double on time, fixed boolean operations bug
  20220102  V1.03: b Interval2 counter was missing always 1 minute, Clean Code remove ToDos
  20220107  V1.04: c On error activate red led, show error permanently on display until quit by red switch
  20220107  V1.05: c Do not reset bError automatically, send text on Err channel on startup
   

**************************************************************************/

#include <Arduino.h>
#include <ArduinoOTA.h>
//#define DEBUG
#include <Wire.h>
#include <Adafruit_MCP4725.h>
#include <ESP8266WiFi.h>
#include <ArduinoJson.h>
#include <PubSubClient.h> //MQTT
#include <LiquidCrystal_I2C.h>
#include <BH1750.h>

#include "D:\Arduino\HomeAutomationSecrets.h"
//libs for DS18B20
#include "Spi.h"
#include <DallasTemperature.h>
#include "PCF8574.h"

const String sSoftware = "ValveCtrl V1.05";

/***************************
 * LCD Settings
 **************************/
LiquidCrystal_I2C lcd(0x27, 20, 4); // set the LCD address to 0x27 for a 16 chars and 2 line display
/* I2C Bus */
//if you use ESP8266-01 with not default SDA and SCL pins, define these 2 lines, else delete them
// use Pin Numbers from GPIO e.g. GPIO4 = 4
// For NodeMCU Lua Lolin V3: D1=GPIO5 = SCL D2=GPIO4 = SDA set to SDA_PIN 4, SCL_PIN 5, D7=13
#define SDA_PIN 4
#define SCL_PIN 5
#define ONE_WIRE_PIN 12

/***************************
 * TempSensor Settings
 **************************/
//pin GPIO2 (NodeMCU) D4 =  GPIO4  (ESP12-F Modul) use GPIO Number, when using higher pins may need to setup INPUT_PULLUP
//const byte bus = 12;
#define SENSCORR1A -0.3 //calibration
OneWire oneWire(ONE_WIRE_PIN);
DallasTemperature sensoren(&oneWire);
//Array to store temp sensor adress
DeviceAddress TempSensAdress;
//Datenstruktur f�r den Datenaustausch
#define CHAN 5 // device channel 1 = Developmentboard 2 = ESP gel�tet 5 = Valve Control

/***************************
 * Ctrl PCB Settings
 **************************/
#define LEDGB P4
#define LEDGN P5
#define LEDBL P6
#define LEDRT P7
#define SWGB P0
#define SWGN P1
#define SWBL P2
#define SWRT P3

byte gradeChar[8] = {
    0b00111,
    0b00101,
    0b00111,
    0b00000,
    0b00000,
    0b00000,
    0b00000,
    0b00000};

struct DATEN_STRUKTUR
{
  int chan = CHAN;
  float temp1 = -127; //Aussen A
  float temp2 = -127; //Aussen B
  float fHumidity = -1;
  float fVoltage = -1; //Batterie Sensor
};

/***************************
 * WiFI and MQTT Settings
 **************************/
WiFiClient MQTT_client;
PubSubClient mqttClient(MQTT_client);
//SubChannel ValvPos to receive positions from master
//SubChannel ValvMeasurement to send temperatures, volt, current ....

#define USERNAME "TestName/"
#define T_CHANNEL "ValveControl"
#define T_COMMAND "command"
#define MYHOSTNAME "ValveControl"

/***************************
 * Measurement Variables
 **************************/
DATEN_STRUKTUR data;
const int mqttRecBufSiz = 50;
char mqttBufValvPos[mqttRecBufSiz];
int iValvPosSetP;          //Setpoint Valve Position
int iManMode = 6;          //6 = auto, 0-5 manual valve setting
int iAutoValue = 5;        //value for valve from MQTT keeps always last updated value
int iValveIntervalCnt = 0; //Counter valve interval in seconds
bool bValveOn = true;      //Valve on/off used for interval
int iActValvPos = 5;       //Valve position actually set

/***************************
 * Timing
 **************************/

const unsigned long ulMQTTInterval = 3 * 1000UL; //call MQTT server
long lMQTTTime = 0;
const unsigned long ulValveSetInterval = 60 * 1000UL; //Normal 60 set valve, measure temp, send mqtt  60 sec
long lValveSetTime = 0;
const unsigned long ulUpdateLCDInterval = 0.3 * 1000UL; //normal 1 Write text on LCD, get button, count time for valve interval, do not change
long lUpdateLCDTime = 0;
int iValvInterval2 = 4;                  //interval valve value in minutes (depending on ulValveSetInterval set to 60) 5 minutes on, can be changed per mqtt remotely
int iValvInterval1 = iValvInterval2 * 2; //interval valve value 1

/***************************
 * Digital Analog Converter
 **************************/

Adafruit_MCP4725 dac;

int iMCP4725Adr = 0x60;
int iMCPMaxCode = 4096; //code for max output
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

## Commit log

2020-10-19 Project Valve Control added
2020-10-19 Version Numbers and comments corrected
    [RemoteDisplay.cpp, ValveControl.cpp, main.cpp]
2020-10-20 + Project currentMeasurement
2020-11-02 +I2C Scanner project
2020-11-02 c I2C Scanner correct wire
    [main.cpp]
2020-11-02 - Tasmota c Adafruit sample current measurement works
2020-12-30 +2 Temp Sensors and publish one to mqtt
2020-12-30 + PIN description
2021-01-01 c LCD in subfunction, Error Msg
    [main.cpp]
2021-01-02 +light sensor for LCD
2021-01-02 + Button select
2021-06-29 New Project Lightning Sensor
2021-08-21 Div changes Lightning Sensor
2021-08-21 Valve Control BOM for PCB added
    [BOM_PCB_HeaterFlowRegulator_2021-07-10.csv]
2021-08-26 Test PCF8575 with LED works
2021-08-29 Tempsensor und Taster gehen
2021-08-30 Light Sensor, LCD flicker bug solved
    [ValveControl.cpp]
2021-08-30 Code cleaning, Error handling
    [ValveControl.cpp]
2021-11-27 Ctrl PCB Files added
    [BOM_HeaterFlowRegulatorControlPCB_2021-11-20.csv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]
2021-11-27 LED Test sucessfull
2021-11-27 Switches connected to LEDs Switch 0 controls temp
2021-12-25 PCB output for Fusion 360
    [ControlPCB.dxf, ControlPCBTopLayer.dxf, PCB_HeaterFlowRegulatorControlPCB_2021-12-02.dxf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]
2021-12-30 Cleanup Code LED activated
2021-12-30 LEDs functional
2021-12-30 Switches functional, light sensor functional
2022-01-07 Error Messages quit with red button
    [ValveControl.cpp]
2022-04-09 Additional sql queries, include link corrected, distinguish between homeserver and weather station in comment
    [ValveControl.cpp, main.cpp]
2022-08-20 Blink Test added
    [BOM_HeaterFlowRegulatorControlPCB_2022-07-19.csv, BOM_PCB_EspNowHub_2022-07-19.csv, BOM_PCB_EspNowHub_2022-07-19.xlsx]
2022-09-18 Test Ctrl Board and Text
2022-09-25 - removed temp sensor code
2022-09-25 +BMP180 pressure sensor connected
2022-09-25 +Recieve Sensor Data via ESP NOW
2022-12-25 Change Switches to number
2023-01-01 rename maint to ESPNowHub, switch Wifi AP
2023-01-11 Draw Temp Sensor 5 on Display
2023-01-15 c Use array for sensor data
2023-01-28 +MAC address, display info on new sensor received
2023-01-29 c no serial com yet but bugfix for first display
    [ESPNowHub.cpp]
2023-01-29 added sensor member bSensorRegistered
2023-01-30 +Hardware PCB Files
    [BOM_EspNowHub_2023-01-29.csv]
2023-02-04 c Timer Names
2023-02-04 e SensorRec was not set to true
2023-02-04 c local sensor set true on read
2023-02-11 c all sensors float /100
2023-02-12 Sensor 5 now using array
2023-02-12 + sensor5 capabilities using bit mask
2023-02-12 c send sensor capabilities over serial
2023-02-12 c send only valid data correct checksum
    [ESPNowHub.cpp, ESPWLANHub.cpp, HomeAutomationCommon.h]
2023-02-12 c value plausibility check for iAtmo corrected
    [ESPNowHub.cpp, ESPWLANHub.cpp, HomeAutomationCommon.h]
2023-02-12 i works with 2 different sensors
2023-02-12 + debounce and optimize switch reaction
2023-02-12 Base menu, drawing frames for sensors, switch tim
2023-10-15 PCB and Mechanics
    [PCB_EspNowHub_2023-02-25.dxf]
2023-10-15 Change LED and Switch order
2023-10-15 Light Sensor activated
2023-10-18 Light Sensor, Atmos correction
    [ESPNowHub.cpp]
2023-12-17 Do not send mqtt if sensor not in use
2024-01-01 +read sensor to serial out
2024-01-02 Format code add sensor 6
2024-01-04 Send all light sensor values. Display version and lux
2024-01-05 sensor capabilites from sensor over espnow
2024-01-20 Add humidity sensor serial out
2024-03-10 Change Librarz in WlanThermoHumidLight. New esp32s3 Test
2024-03-16 Test with timer
2024-03-17 ESP32-S3 Tests to Workspace
2024-05-27 S3 test changes
    [BOM_ThermoExtSensorHumiBatt_2024-05-05.csv]
2024-06-01 Data struct for different sensors
2024-07-07 BOM added
    [BOM_ThermoExtSensorHumiBatt_2024-07-04.csv, BOM_ThermoExtSensorHumiBatt_2024-07-04.xlsx]
2024-07-07 configuration for Sensor 1
2024-07-07 Battery correction factor Sensor 1
    [ESPNowHub.cpp]
2024-07-10 Temp Sensor calibration
